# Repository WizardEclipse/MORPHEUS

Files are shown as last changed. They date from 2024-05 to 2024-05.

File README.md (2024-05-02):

# MORPHEUS
## Blue Pill Diagnostics Tool

Morpheus is a stand-alone diagnostic tool for the STM32 "bluepill" microcontroller. The purpouse of this project is to develop a device, running on an STM32 that can validate the operation of other STM32 boards.

#### Current Design:
Morpheus will run on an STM32 called Paulo. Paulo will have a one-to-one connection to the testboard. It will:
- Validate GPIO pins
- Validate PWM functionality
- Validate ADC functionality
- Have visual indicators of the progress and functionality of the testboard. This can potentially include: and OLED/LCD screen displaying progress of tests, and error codes when a fault is found. LED lights to visualise the operation of the GPIO pins. A buzzer to verify the operation of the PWM pins, some kind of visual guide for ADC functinality.

### **Todo:**
- Make sequence diagram
- Make circuit diagram

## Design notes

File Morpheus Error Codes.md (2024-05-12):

# Morpheus Error Codes:

## Index:
- 0xx - Comms
- 1xx - GPIO
- 2xx - PWM
- 3xx - ADC
- 4xx - Fatal Error

#### 0xx Error Codes:
- 001 - Paulo to Testi handshake failed
- 002 - Testi to Paulo handshake failed
- 003 - UART time out
- 004 I2C test start/stop
- 005 I2C pins set
- 006 I2C pin time out
- 007 I2C corrupted
- 008 I2C time out

#### 1xx GPIO Error Codes:
- 1(00 - 28) - GPIO pin test failure

#### 4xx Fatal Error Codes:

- 400 -  Flashing Failure

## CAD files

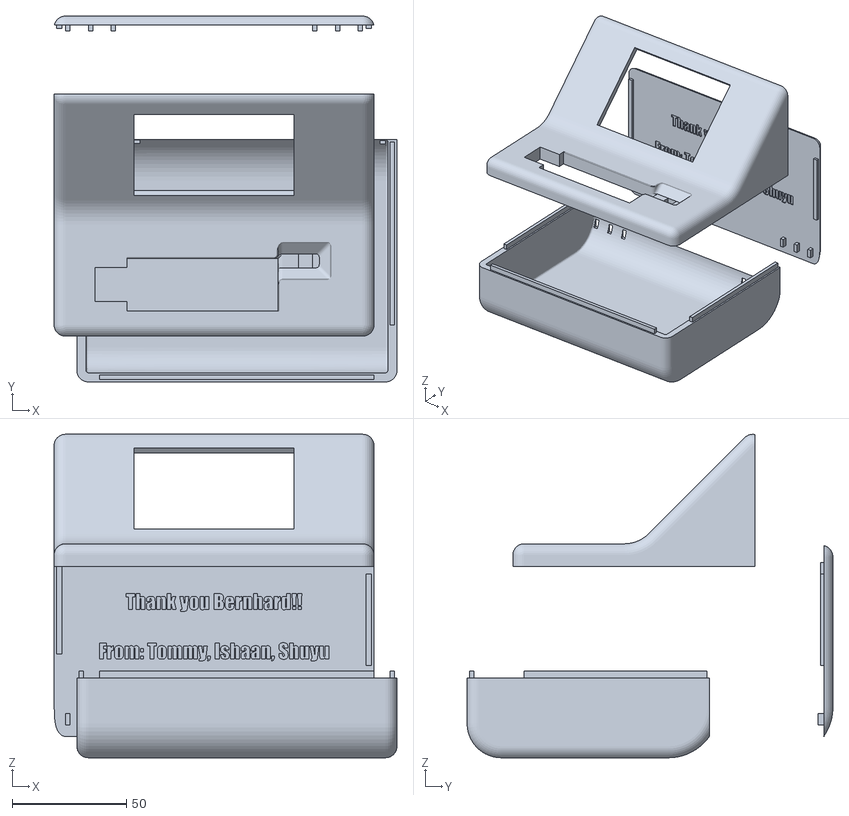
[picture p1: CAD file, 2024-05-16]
morpheus v6.stl
150.0 x 160.0 x 141.5

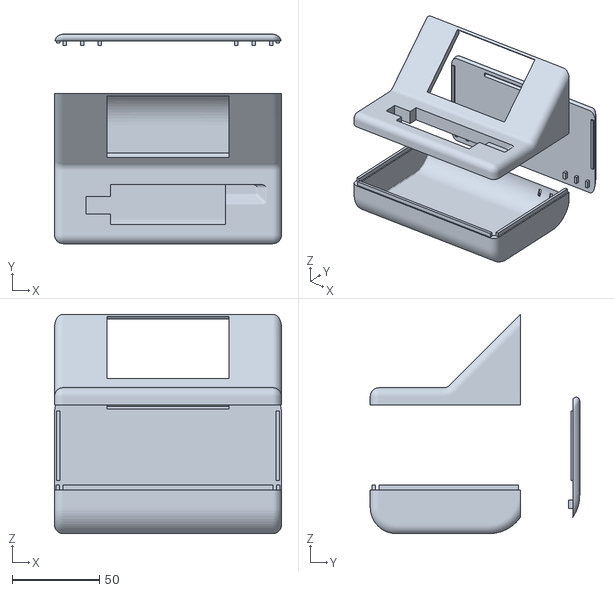
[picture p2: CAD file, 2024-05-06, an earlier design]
morpheus v2.stl
130.0 x 120.0 x 125.6

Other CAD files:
morpheus v6.f3d

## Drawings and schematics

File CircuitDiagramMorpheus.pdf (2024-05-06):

# PAUL 39 -

### PBO-

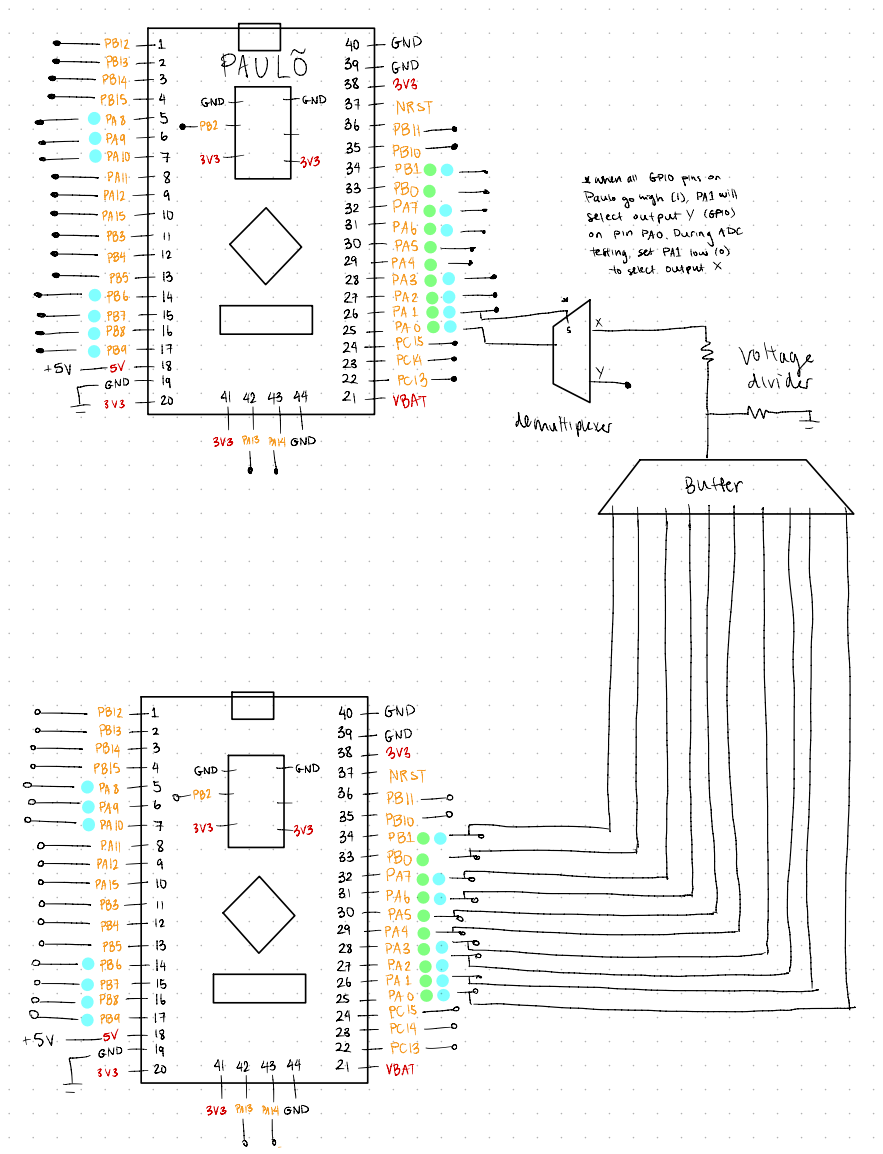
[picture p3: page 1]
GND; GND -; END; NRST ·; PBII ⁻; PBL; PBIO -; *When all; GP10 pins or; go high (1),; PA1 will; 30- PAS-; pin PAO .; During ADC; testing,; PBS; Pat; PBA; PAO; PCIS -; X voltage ⁻; dIVIder; 3V3 PA13 PA14 GND; VBAT; demultiplexer; PBIS; NRST; PBII-o; PAIO -; PBIO-0 3V3-; · PBO; 31 - PAG 0- PB3; PBS &; PBi; PCIS; 3V3 PAB 4114 GND ↓ !

Paulo
select output Y (GPIO)

to select output ·

set PAI low 10)

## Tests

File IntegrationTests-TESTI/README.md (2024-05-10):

New Linux install,
apt install all the basics
install python(>3.6),pip,pyenv and other python basics (not needed but helpful)
intall stlink-tools to see into blupills memory 
(for Raspberry Pi, use the built in Add/Remove Software tool from the Preferences tab top right, DO NOT MAKE yourself unless highly skilled or want to waste all the beutiful sunlight)
install PlatformIO Core (CLI):
	curl -fsSL -o get-platformio.py https://raw.githubusercontent.com/platformio/platformio-core-installer/master/get-platformio.py
	python3 get-platformio.py

	install Shell Commands:
	
	mkdir -p /usr/local/bin
	ln -s ~/.platformio/penv/bin/platformio /usr/local/bin/platformio
	ln -s ~/.platformio/penv/bin/pio /usr/local/bin/pio
	ln -s ~/.platformio/penv/bin/piodebuggdb /usr/local/bin/piodebuggdb

	install 99-platformio-udev.rules
	curl -fsSL https://raw.githubusercontent.com/platformio/platformio-core/develop/platformio/assets/system/99-platformio-udev.rules | sudo tee /etc/udev/rules.d/99-platformio-udev.rules
	sudo service udev restart
	sudo usermod -a -G dialout $USER
	sudo usermod -a -G plugdev $USER

TODO: make requirements.txt and make this more step-by-step 

Setting up project:

make project directory
cd into project 
pio project init --board bluepill_f103c8

paste code that we want to go into testi in src
make sure to configure platform.ini well, here is what works:

	[env:bluepill_f103c8]
	platform = ststm32
	board = bluepill_f103c8
	framework = arduino
	upload_flags = -c set CPUTAPID 0x2ba01477
	lib_deps = 	Adafruit SSD1306
			AdafruitBusID
	upload_protocol = stlink
	debug_tool = stlink

In above example external libraries were used in lib deps, make sure they are seperated by different lines and properly tabbed (pythonic)

pio run <- only need once during project inti, will build the environment, and install libraries/frameworks as needed based on .ini
pio run --target upload  <- will upload code to bluepill

Python button automation:
Made interrupt based program, uses gpio pin 21 (bottom right), as input pullup resistor. Debouncing in place. Also 1 minute 'cool down' so kids arent spamming the 'diagnose' button when they're frustrated.

everytime button is pressed the build files are cleared and rebuilt then reflashed onto bluepill. Takes about 50 secs in my tests. We can remove this so that we are'nt necessarily rebuilding from scratch all the time. (probably good to do once we have all the proper testi code figured out)

So far all works great, BUT you have to fist run the python file by going: python3 morphy_button_inter.py

Creating System md service to run on startup and background:

sudo nano /etc/systemd/system/morpheus_flash.service

[Unit]
Description=Run Python script to flash blue pill on Button Press
After=multi-user.target

[Service]
Type=simple
User=pi
ExecStart=/usr/bin/python3 /home/pi/Desktop/flash_to_testi/morphy_button_inter.py

[Install]
WantedBy=multi-user.target

sudo systemctl daemon-reload
sudo systemctl enable morpheus_flash.service
sudo systemctl start morpheus_flash.service

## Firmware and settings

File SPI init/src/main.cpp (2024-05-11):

#include <SPI.h>

#define SS_PIN PA4  // Define the Slave Select pin
#define LED_PIN PC13  // Define LED pin (built-in LED on STM32 Blue Pill)

void setup() {
  pinMode(SS_PIN, OUTPUT); // Set the SS pin as an output
  pinMode(LED_PIN, OUTPUT); // Set the LED pin as an output
  digitalWrite(SS_PIN, HIGH); // Start with the slave deselected
  digitalWrite(LED_PIN, LOW); // Ensure LED is off initially
  
  Serial.begin(115200); // Start serial communication at 115200 baud
  SPI.begin(); // Initialize SPI communication
  SPI.setClockDivider(SPI_CLOCK_DIV16); // Set clock divider for appropriate SPI speed
}

void loop() {
  digitalWrite(SS_PIN, LOW); // Select the slave
  byte sentData = 0x35; // Data to send
  byte receivedData = SPI.transfer(sentData); // Send data to the slave and receive response
  digitalWrite(SS_PIN, HIGH); // Deselect the slave

  // Check if the received data is what we expect (0x12)
  if (receivedData == 0x12) {
    digitalWrite(LED_PIN, HIGH); // Turn LED on
    delay(100); // Keep it on for 100 ms
    digitalWrite(LED_PIN, LOW); // Turn LED off
  }

  Serial.print("Sent: ");
  Serial.print(sentData, HEX); // Print sent data in hexadecimal
  Serial.print(", Received: ");
  Serial.println(receivedData, HEX); // Print received data in hexadecimal
  delay(2000); // Wait for two seconds
}




// #include <SPI.h>

// #define SS_PIN PA4  // Define the Slave Select pin
// #define LED_PIN PC13  // Define LED pin (built-in LED on STM32 Blue Pill)

// volatile byte receivedData;
// volatile bool newData = false;

// void setup() {
//   pinMode(SS_PIN, INPUT); // Set the SS pin as an input to detect master's selection
//   pinMode(MISO, OUTPUT); // Set MISO as output
//   pinMode(LED_PIN, OUTPUT); // Set the LED pin as an output
//   digitalWrite(LED_PIN, LOW); // Ensure LED is off initially
//   Serial.begin(115200); // Start serial communication

//   SPI.begin(); // Start SPI in slave mode
//   SPI.attachInterrupt(); // Enable SPI interrupt to handle incoming data
// }

// void SPI_ISR() {
//   receivedData = SPI.transfer(0x12); // Send back 0x12 whenever data is received
//   newData = true; // Set flag when new data is received
//   digitalWrite(LED_PIN, HIGH); // Turn LED on
//   delay(100); // Keep it on for 100 ms
//   digitalWrite(LED_PIN, LOW); // Turn LED off
// }

// void loop() {
//   if (newData) {
//     Serial.print("Received Data: ");
//     Serial.println(receivedData, HEX); // Print received data
//     newData = false; // Reset the flag
//   }
// }

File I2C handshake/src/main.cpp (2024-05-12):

// //PAULO

#include <Wire.h>
#include <Arduino.h>

const int LED_PIN = PC13;
const int I2C_SLAVE_ADDR = 9;

void setup() {
  pinMode(LED_PIN, OUTPUT);
  Serial.begin(9600);
  Wire.begin();  // Start I2C as master
}

void blinkError(int code) {
  for (int i = 0; i < code; i++) {
    digitalWrite(LED_PIN, HIGH);
    delay(300);
    digitalWrite(LED_PIN, LOW);
    delay(300);
  }
  delay(500);  // Pause between error codes
}

void loop() {
  Serial.println(004);  // Send code 004 to Testi via UART
  delay(500);  // Wait for Testi to process
  
  // Wait for response code 005 via UART
  unsigned long startTime = millis();
  while (!Serial.available() && millis() - startTime < 2750);
  if (Serial.available()) {
    int code = Serial.parseInt();
    if (code == 005) {
      // Send 005 to Testi via I2C
      Wire.beginTransmission(I2C_SLAVE_ADDR);
      Wire.write(005);
      Wire.endTransmission();

      // Wait for response 004 via I2C
      Wire.requestFrom(I2C_SLAVE_ADDR, 1);
      startTime = millis();
      while (!Wire.available() && millis() - startTime < 2750);
      if (Wire.available()) {
        int response = Wire.read();
        if (response == 004) {
          // Success, blink LED quickly three times
          blinkError(3);
        } else {
          // Error code 008
          blinkError(8);
        }
      } else {
        // No response received, error code 008
        blinkError(8);
      }
    } else {
      // Incorrect or no code received, blink LED error 5 times
      blinkError(5);
    }
  } else {
    // Timeout waiting for 005, blink LED error 8 times
    blinkError(8);
  }
  
  delay(5000);  // Delay before next loop iteration
}



// Testi


// #include <Wire.h>
// #include <Arduino.h>

// const int LED_PIN = PC13;
// const int I2C_SLAVE_ADDR = 9;

// void receiveEvent(int howMany) {
//   while (Wire.available()) {
//     int code = Wire.read();
//     if (code == 005) {
//       // Send 004 back to Paulo if received 005
//       Wire.write(004);
//     }
//   }
// }

// void requestEvent() {
//   Wire.write(005);  // Send 005 when requested
// }

// void setup() {
//   pinMode(LED_PIN, OUTPUT);
//   Serial.begin(9600);
//   Wire.begin(I2C_SLAVE_ADDR);  // Start I2C as slave on address 9
//   Wire.onReceive(receiveEvent);
//   Wire.onRequest(requestEvent);
// }

// void blinkLED(int times) {
//   for (int i = 0; i < times; i++) {
//     digitalWrite(LED_PIN, HIGH);
//     delay(200);
//     digitalWrite(LED_PIN, LOW);
//     delay(200);
//   }
// }


// void loop() {
//   if (Serial.available()) {
//     int code = Serial.parseInt();
//     if (code == 004) {
//       // Received 004 from Paulo, send 005 via UART
//       Serial.println(005);
//       blinkLED(2);  // Blink to show received 004
//     }
//   }
// }

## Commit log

2024-05-01 Initial commit GPIO drag and drop
    triggers GPIO pins A0-A15 and B0,B1,B3-B13 and digital output and cycles in switching to HIGH and does same to LOW
2024-05-02 Added current design specs
2024-05-02 PWM tester
    Play jingle bells, with each pin on the stm32 playing a different note, tests all pins.
    if one note is quieter or does not play may indicate fault in that pin.
2024-05-06 Morpheus enclosure CAD files
    finished version of morpheus enclosure in 4 parts
    [morpheus v2.stl]
2024-05-10 UART set up
    one board waits for the other to blink before it blinks
2024-05-10 i2c tester
    init i2c with a master and slave.
2024-05-10 Testi flash on button press
2024-05-10 SPI init
2024-05-11 Implement initial TESTI side code
    morphy_button_inter
    Flasher working on button press
    Uses pin value to communicate flash states to Paulo
    main.c
    Implemented UART validation through Handshake with Paulo
2024-05-11 Implement initial PAULO side code
    Integration with Adafruit mini OLED
    Displays Flash state with comms through RPi
    Tests UART by implementing PAULO-TESTI handshake
2024-05-11 Update Error Code to follow Error docs
    [main.cpp, morphy_button_inter.py]
2024-05-11 gpio pin test
    flashing works, UART handshake works, GPIO error code works, gpio testing does not work
2024-05-11 11/05/2024 4:01 AM flash works, UART handshake works, GPIO UART error code works, GPIO testing bus does not work
    [main.cpp, morphy_button_inter.py]
2024-05-11 11/05/2024 4:07 AM flash works, UART handshake works, GPIO UART error code works, GPIO testing bus does not work
    [main.cpp]
2024-05-11 Move code to loop. Fix flashFlag functionality.
    [main.cpp]
2024-05-12 Added Flashing Error Test
    [morphy_button_inter.py]
2024-05-12 Added Standby, flashing error test, rewired RPi-Paulo
    [main.cpp]
2024-05-12 this is not working
    not working
    [main.cpp]
2024-05-13 Working 16 pin gpio tester 2 multiplexers
2024-05-13 Working 32 pin GPIO tester
2024-05-14 Mostly working 32 pins, last channel on MUX error.
    [main.cpp]
2024-05-16 Morpheus Final CAD Files
    [morpheus v6.f3d, morpheus v6.stl]
